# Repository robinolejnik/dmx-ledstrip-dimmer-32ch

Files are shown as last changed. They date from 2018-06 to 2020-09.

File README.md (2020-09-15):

# 32ch DMX LED Strip Dimmer

Arduino Mini and TLC5940 based 32 channel 12V PWM dimmer with [DMX512](https://en.wikipedia.org/wiki/DMX512) and [RDM](https://en.wikipedia.org/wiki/RDM_(lighting)) support.

## Table of contents
* [Features](#features)
* [Building and connecting the PCB](#building-and-connecting-the-pcb)
* [Installing the Software](#installing-the-software)
* [Setting the DMX channel](#setting-the-dmx-channel)
* [Write your own Software](#write-your-own-software)
* [Arduino Pin Configuration](#arduino-pin-configuration)
* [Contributing](#contributing)
* [See also](#see-also)
* [License](#license)

## Features
- 32 channels
- several amps current capability per channel
- high PWM frequency
- [DMX512](https://en.wikipedia.org/wiki/DMX512) with [RDM](https://en.wikipedia.org/wiki/RDM_(lighting)) support
- control LEDs, LED-Strips, Lamps, Motors, Relays, ...

## Building and connecting the PCB
The double sided PCB has surface mounted components on both sides. All resistors and capacitors are 0805 sized parts.
Screw terminals are available for all connections.

### Installing the Software

#### Connecting the Programmer
On the PCB, there is no dedicated programming connector. Instead, directly connect a serial adapter to the Arduino Pro Mini. Make sure that no DMX device is connected to the PCB.

#### Libraries
Install the required libraries within the Arduino IDE
* [tlc5940](https://github.com/PaulStoffregen/Tlc5940) Control of the two TLC5940 ICs
* [dmxserial2](https://github.com/mathertel/DmxSerial2) Used to handle DMX and RDM decoding

Open the [Sketch](dmx_led_strip_dimmer_32ch.ino) with the Arduino IDE, change the DMX address if needed, select the correct serial port and Hardware (Arduino Pro Mini or Arduino Mini) and click Upload.

### Setting the DMX channel
The DMX channel can be preset in the Arduino source code. Later, it can only be changed via RDM ([Remote Device Management](https://en.wikipedia.org/wiki/RDM_(lighting))) commands.

## Write your own Software
The PWM signals are created by two chained TLC5940 PWM LED drivers. Output 1-16 of U7 maps to Output 1-16 on the PCB, output 1-16 of U8 maps to Output 17-32 of the PCB. Per channel, one 74HC04 inverter is used. It is necessary because the PWM controller cannot completely turn off a directly connected N-channel MOSFET. It cannot get it's PWM count down to 0. By inverting the PWM signal, the PCB output can be turned off by fully turning on the TLC5940 channel.

### Arduino pin configuration

| Pin | Function |
| --- | --- |
|  0  | RxD (DMX) |
|  1  | TxD (DMX) |
|  2  | RS485 (DMX) Direction |
|  3  | GSCLK (TLC5940) |
|  9  | XLAT (TLC5940) |
| 10  | BLANK (TLC5940) |
| 11  | SIN (TLC5940) |
| 13  | SCLK (TLC5940) |

Unlisted pins are not connected. The internal voltage regulator on the Arduino Mini Board is not used.

Take a look at the [schematic](schematic.pdf) too. It should clarify things further.

## Contributing
If you want to improve something, feel free to create a pull request.

One thing to optimize is the linear voltage regulator. Maybe someone is interested in fitting a suitable step down converter into the PCB?

## See also

* [TLC5940 datasheet](https://www.ti.com/lit/ds/symlink/tlc5940.pdf)
* [Wikipedia DMX512](https://en.wikipedia.org/wiki/DMX512)
* [Wikipedia RDM](https://en.wikipedia.org/wiki/RDM_(lighting))

## License
[MIT](https://choosealicense.com/licenses/mit/)

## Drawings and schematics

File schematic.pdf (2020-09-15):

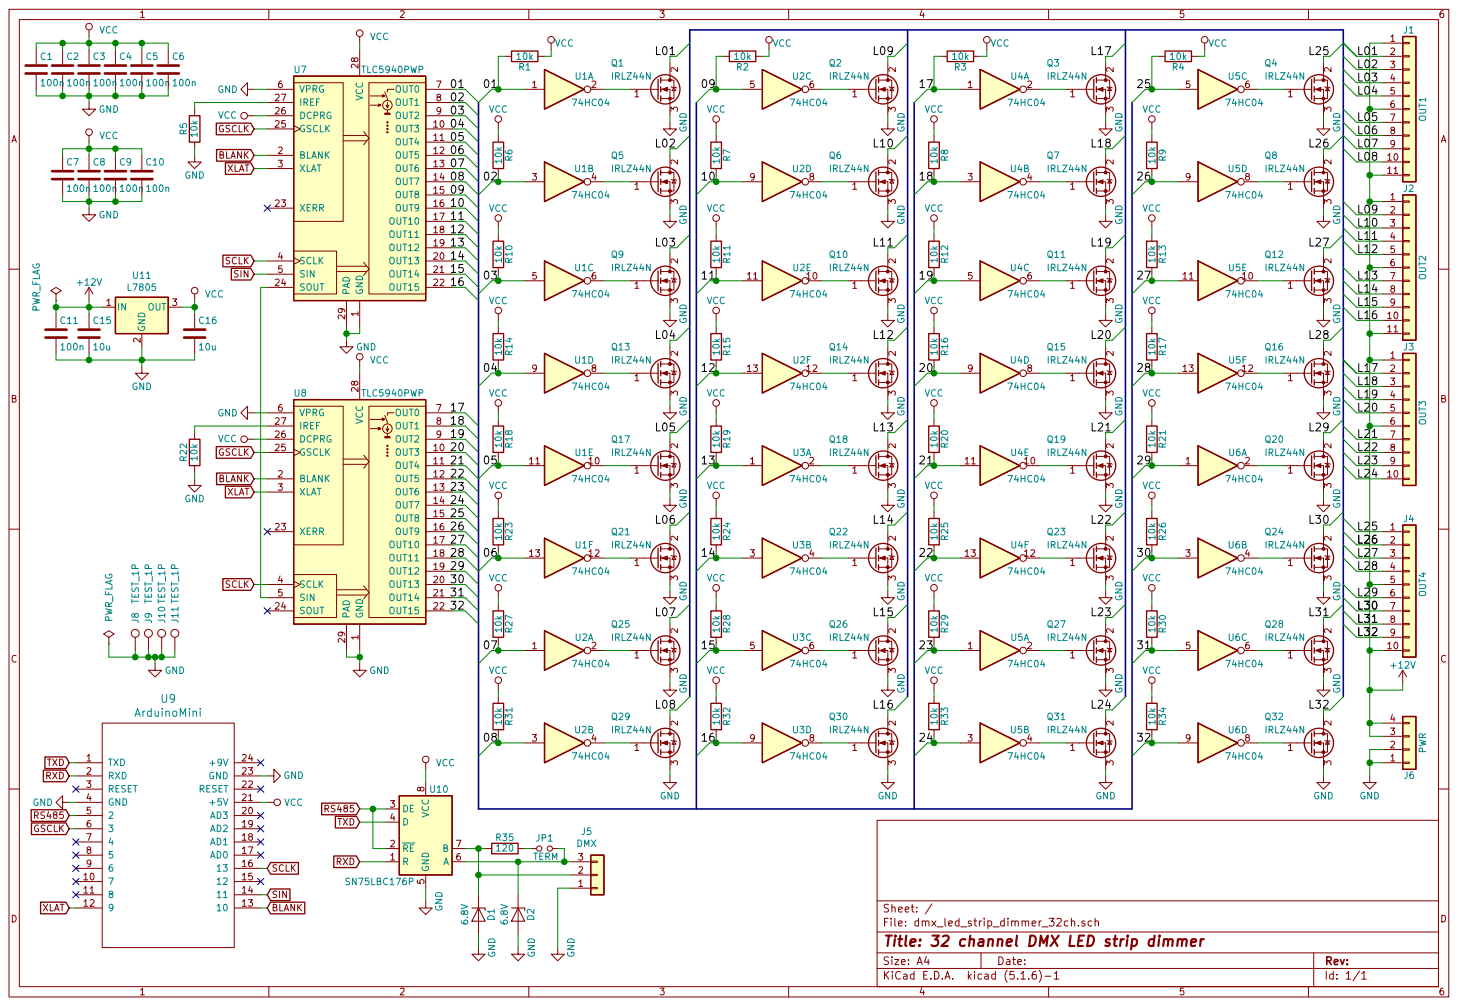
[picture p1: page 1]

1 OUT3 10 OUT4 11 OUT5 12 OUT6 13 OUT7 14 OUT8 15 OUT9 16 OUT10 17 OUT11 18 OUT12 19 BLANK 2 OUT13 20 OUT14 21 OUT15 22 XERR 23 SOUT 24 GSCLK 25 DCPRG 26

File: dmx_led_strip_dimmer_32ch.sch Sheet: /
Id: 1/1 Title: 32 channel DMX LED strip dimmer

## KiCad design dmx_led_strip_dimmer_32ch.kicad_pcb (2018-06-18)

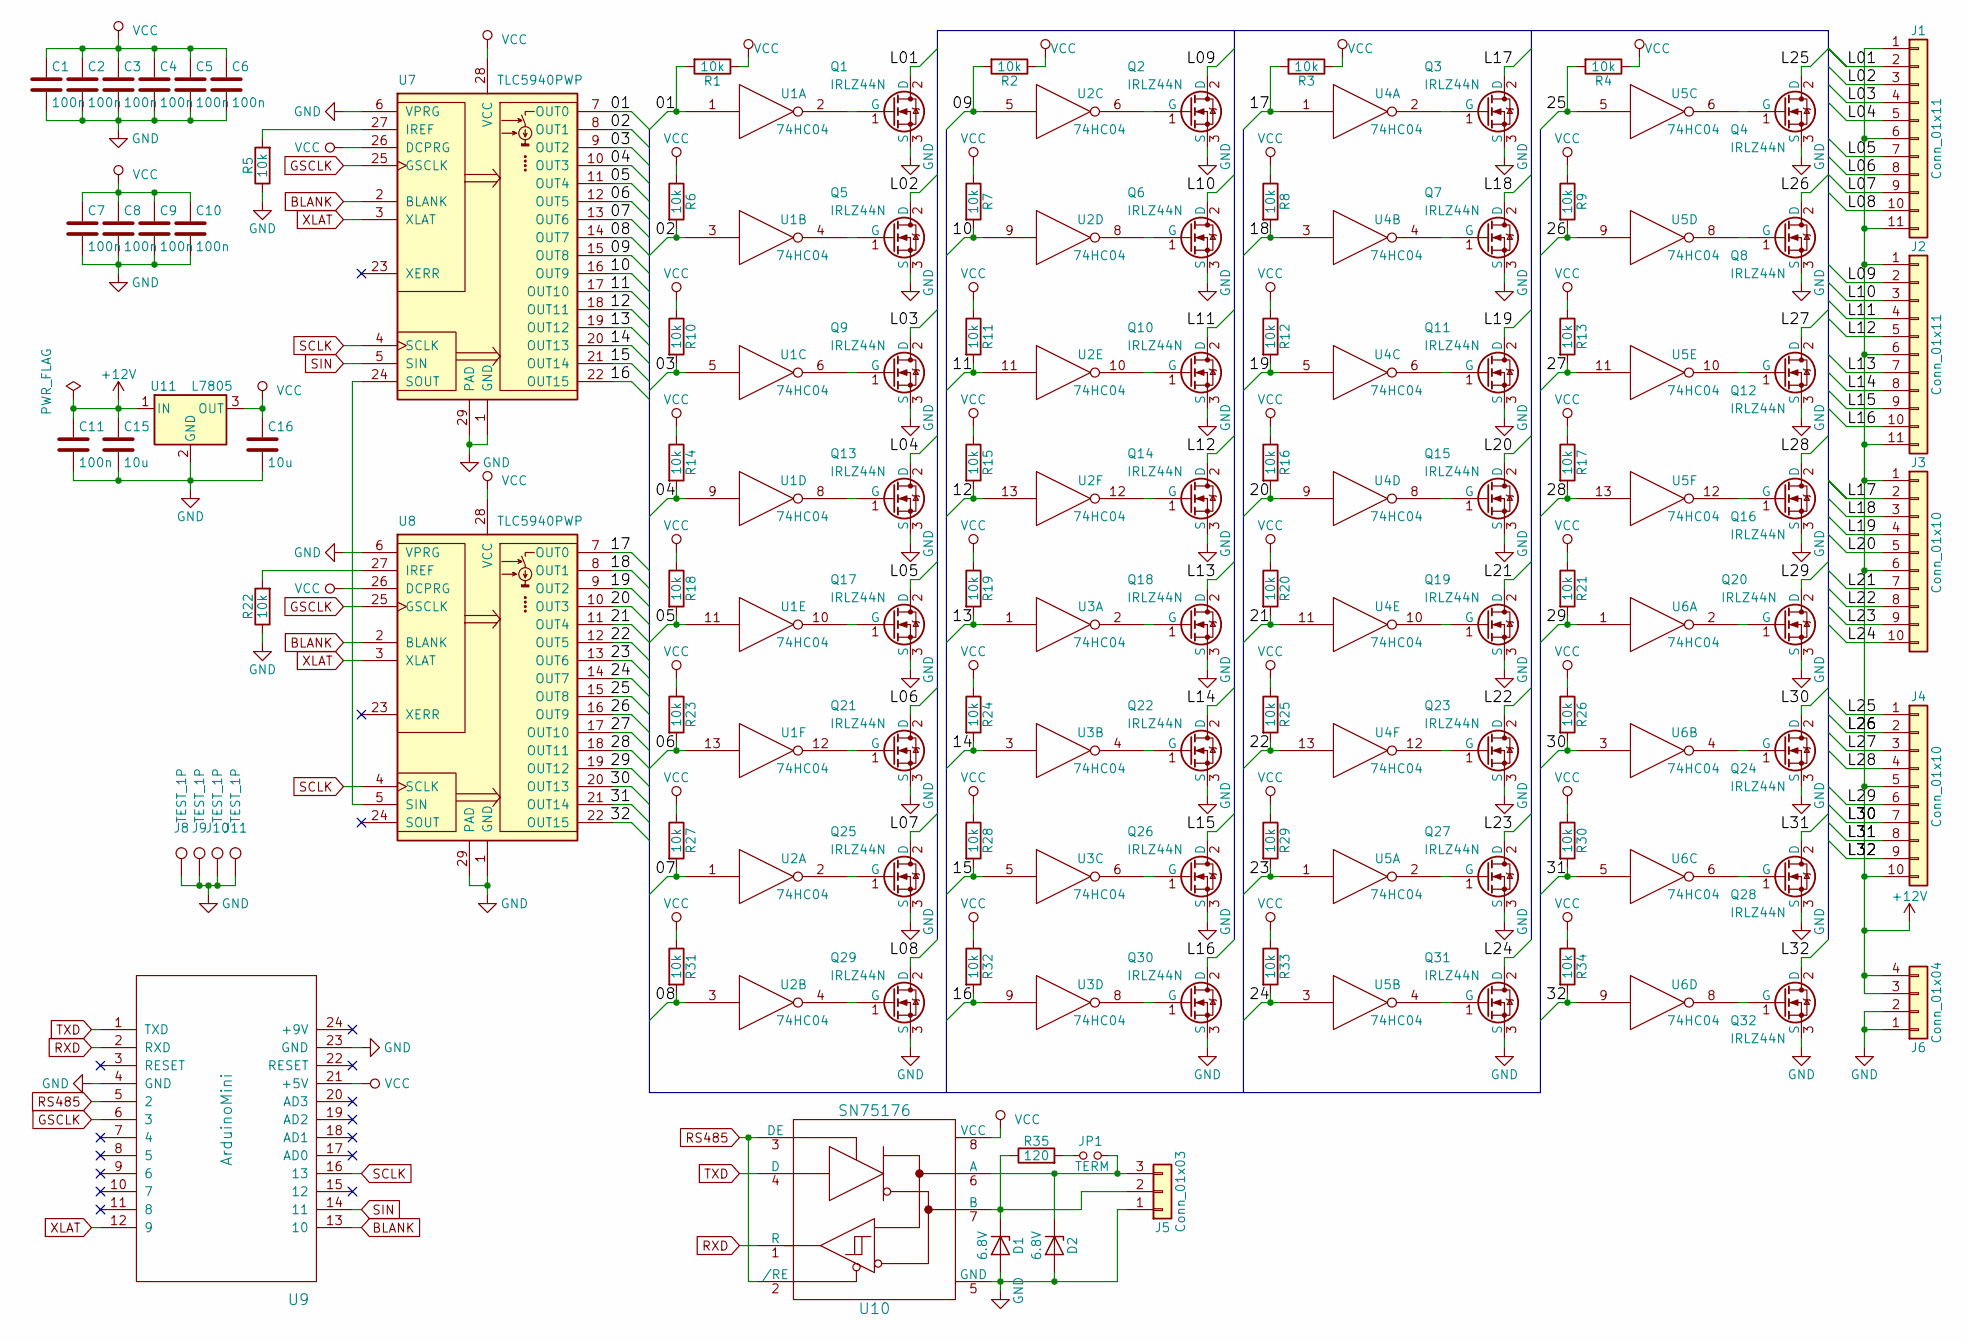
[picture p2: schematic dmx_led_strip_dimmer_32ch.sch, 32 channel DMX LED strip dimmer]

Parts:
C1, C2, C3, C4, C5, C6, C7, C8, C9, C10, C11: 100n; C_0805_HandSoldering
C15, C16: 10u; C_0805_HandSoldering
D1, D2: 6.8V; D_MiniMELF
J1, J2: Conn_01x11; TerminalBlock_Pheonix_MKDS1.5-11pol
J3, J4: Conn_01x10; TerminalBlock_Pheonix_MKDS1.5-10pol
J5: Conn_01x03; TerminalBlock_Pheonix_MKDS1.5-3pol
J6: Conn_01x04; TerminalBlock_Pheonix_MKDS1.5-4pol
J8, J9, J10, J11: TEST_1P; MountingHole_3.2mm_M3_ISO7380_Pad
JP1: TERM; Pin_Header_Straight_1x02_Pitch2.54mm
Q1, Q2, Q3, Q4, Q5, Q6, Q7, Q8, Q9, Q10, Q11, Q12, Q13, Q14, Q15, Q16, Q17, Q18, Q19, Q20, Q21, Q22, Q23, Q24, Q25, Q26, Q27, Q28, Q29, Q30, Q31, Q32: IRLZ44N; TO-220_Vertical
R1, R2, R3, R4, R5, R6, R7, R8, R9, R10, R11, R12, R13, R14, R15, R16, R17, R18, R19, R20, R21, R22, R23, R24, R25, R26, R27, R28, R29, R30, R31, R32, R33, R34: 10k; R_0805_HandSoldering
R35: 120; R_0805_HandSoldering
U1, U2, U3, U4, U5, U6: 74HC04; SOIC-14_3.9x8.7mm_Pitch1.27mm
U7, U8: TLC5940PWP; TSSOP-28_4.4x9.7mm_Pitch0.65mm
U9: ArduinoMini; DIP-24_W15.24mm_LongPads
U10: SN75176; SOIC-8_3.9x4.9mm_Pitch1.27mm
U11: L7805; TO-220-3_Vertical

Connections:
+12V: C11.1, C15.1, J1.1, J1.6, J1.11, J2.1, J2.6, J2.11, J3.1, J3.6, J4.5, J4.10, J6.3, J6.4, U11.1 (IN)
/01: R1.2, U1.1, U7.7 (OUT0)
/02: R6.2, U1.3, U7.8 (OUT1)
/03: R10.2, U1.5, U7.9 (OUT2)
/04: R14.2, U1.9, U7.10 (OUT3)
/05: R18.2, U1.11, U7.11 (OUT4)
/06: R23.2, U1.13, U7.12 (OUT5)
/07: R27.2, U2.1, U7.13 (OUT6)
/08: R31.2, U2.3, U7.14 (OUT7)
/09: R2.2, U2.5, U7.15 (OUT8)
/10: R7.2, U2.9, U7.16 (OUT9)
/11: R11.2, U2.11, U7.17 (OUT10)
/12: R15.2, U2.13, U7.18 (OUT11)
/13: R19.2, U3.1, U7.19 (OUT12)
/14: R24.2, U3.3, U7.20 (OUT13)
/15: R28.2, U3.5, U7.21 (OUT14)
/16: R32.2, U3.9, U7.22 (OUT15)
/17: R3.2, U4.1, U8.7 (OUT0)
/18: R8.2, U4.3, U8.8 (OUT1)
/19: R12.2, U4.5, U8.9 (OUT2)
/20: R16.2, U4.9, U8.10 (OUT3)
/21: R20.2, U4.11, U8.11 (OUT4)
/22: R25.2, U4.13, U8.12 (OUT5)
/23: R29.2, U5.1, U8.13 (OUT6)
/24: R33.2, U5.3, U8.14 (OUT7)
/25: R4.2, U5.5, U8.15 (OUT8)
/26: R9.2, U5.9, U8.16 (OUT9)
/27: R13.2, U5.11, U8.17 (OUT10)
/28: R17.2, U5.13, U8.18 (OUT11)
/29: R21.2, U6.1, U8.19 (OUT12)
/30: R26.2, U6.3, U8.20 (OUT13)
/31: R30.2, U6.5, U8.21 (OUT14)
/32: R34.2, U6.9, U8.22 (OUT15)
/L01: J1.2, Q1.2 (D)
/L02: J1.3, Q5.2 (D)
/L03: J1.4, Q9.2 (D)
/L04: J1.5, Q13.2 (D)
/L05: J1.7, Q17.2 (D)
/L06: J1.8, Q21.2 (D)
/L07: J1.9, Q25.2 (D)
/L08: J1.10, Q29.2 (D)
/L09: J2.2, Q2.2 (D)
/L10: J2.3, Q6.2 (D)
/L11: J2.4, Q10.2 (D)
/L12: J2.5, Q14.2 (D)
/L13: J2.7, Q18.2 (D)
/L14: J2.8, Q22.2 (D)
/L15: J2.9, Q26.2 (D)
/L16: J2.10, Q30.2 (D)
/L17: J3.2, Q3.2 (D)
/L18: J3.3, Q7.2 (D)
/L19: J3.4, Q11.2 (D)
/L20: J3.5, Q15.2 (D)
/L21: J3.7, Q19.2 (D)
/L22: J3.8, Q23.2 (D)
/L23: J3.9, Q27.2 (D)
/L24: J3.10, Q31.2 (D)
/L25: J4.1, Q4.2 (D)
/L26: J4.2, Q8.2 (D)
/L27: J4.3, Q12.2 (D)
/L28: J4.4, Q16.2 (D)
/L29: J4.6, Q20.2 (D)
/L30: J4.7, Q24.2 (D)
/L31: J4.8, Q28.2 (D)
/L32: J4.9, Q32.2 (D)
BLANK: U7.2 (BLANK), U8.2 (BLANK), U9.13 (10)
GND: C1.2, C2.2, C3.2, C4.2, C5.2, C6.2, C7.2, C8.2, C9.2, C10.2, C11.2, C15.2, C16.2, D1.2 (A), D2.2 (A), J5.1, J6.1, J6.2, J8.1, J9.1, J10.1, J11.1, Q1.3 (S), Q2.3 (S), Q3.3 (S), Q4.3 (S), Q5.3 (S), Q6.3 (S), Q7.3 (S), Q8.3 (S), Q9.3 (S), Q10.3 (S), Q11.3 (S), Q12.3 (S), Q13.3 (S), Q14.3 (S), Q15.3 (S), Q16.3 (S), Q17.3 (S), Q18.3 (S), Q19.3 (S), Q20.3 (S), Q21.3 (S), Q22.3 (S), Q23.3 (S), Q24.3 (S), Q25.3 (S), Q26.3 (S), Q27.3 (S), Q28.3 (S), Q29.3 (S), Q30.3 (S), Q31.3 (S), Q32.3 (S), R5.1, R22.1, U1.7 (GND), U2.7 (GND), U3.7 (GND), U4.7 (GND), U5.7 (GND), U6.7 (GND), U7.1 (GND), U7.6 (VPRG), U7.29 (PAD), U8.1 (GND), U8.6 (VPRG), U8.29 (PAD), U9.4 (GND), U9.23 (GND), U10.5 (GND), U11.2 (GND)
GSCLK: U7.25 (GSCLK), U8.25 (GSCLK), U9.6 (3)
unnamed: D1.1 (K), J5.2, R35.1, U10.7 (B)
unnamed: D2.1 (K), J5.3, JP1.2, U10.6 (A)
unnamed: JP1.1, R35.2
unnamed: Q1.1 (G), U1.2
unnamed: Q2.1 (G), U2.6
unnamed: Q3.1 (G), U4.2
unnamed: Q4.1 (G), U5.6
unnamed: Q5.1 (G), U1.4
unnamed: Q6.1 (G), U2.8
unnamed: Q7.1 (G), U4.4
unnamed: Q8.1 (G), U5.8
unnamed: Q9.1 (G), U1.6
unnamed: Q10.1 (G), U2.10
unnamed: Q11.1 (G), U4.6
unnamed: Q12.1 (G), U5.10
unnamed: Q13.1 (G), U1.8
unnamed: Q14.1 (G), U2.12
unnamed: Q15.1 (G), U4.8
unnamed: Q16.1 (G), U5.12
unnamed: Q17.1 (G), U1.10
unnamed: Q18.1 (G), U3.2
unnamed: Q19.1 (G), U4.10
unnamed: Q20.1 (G), U6.2
unnamed: Q21.1 (G), U1.12
unnamed: Q22.1 (G), U3.4
unnamed: Q23.1 (G), U4.12
unnamed: Q24.1 (G), U6.4
unnamed: Q25.1 (G), U2.2
unnamed: Q26.1 (G), U3.6
unnamed: Q27.1 (G), U5.2
unnamed: Q28.1 (G), U6.6
unnamed: Q29.1 (G), U2.4
unnamed: Q30.1 (G), U3.8
unnamed: Q31.1 (G), U5.4
unnamed: Q32.1 (G), U6.8
unnamed: R5.2, U7.27 (IREF)
unnamed: R22.2, U8.27 (IREF)
unnamed: U7.24 (SOUT), U8.5 (SIN)
RS485: U9.5 (2), U10.2 (/RE), U10.3 (DE)
RXD: U9.2 (RXD), U10.1 (R)
SCLK: U7.4 (SCLK), U8.4 (SCLK), U9.16 (13)
SIN: U7.5 (SIN), U9.14 (11)
TXD: U9.1 (TXD), U10.4 (D)
VCC: C1.1, C2.1, C3.1, C4.1, C5.1, C6.1, C7.1, C8.1, C9.1, C10.1, C16.1, R1.1, R2.1, R3.1, R4.1, R6.1, R7.1, R8.1, R9.1, R10.1, R11.1, R12.1, R13.1, R14.1, R15.1, R16.1, R17.1, R18.1, R19.1, R20.1, R21.1, R23.1, R24.1, R25.1, R26.1, R27.1, R28.1, R29.1, R30.1, R31.1, R32.1, R33.1, R34.1, U1.14 (VCC), U2.14 (VCC), U3.14 (VCC), U4.14 (VCC), U5.14 (VCC), U6.14 (VCC), U7.26 (DCPRG), U7.28 (VCC), U8.26 (DCPRG), U8.28 (VCC), U9.21 (+5V), U10.8 (VCC), U11.3 (OUT)
XLAT: U7.3 (XLAT), U8.3 (XLAT), U9.12 (9)

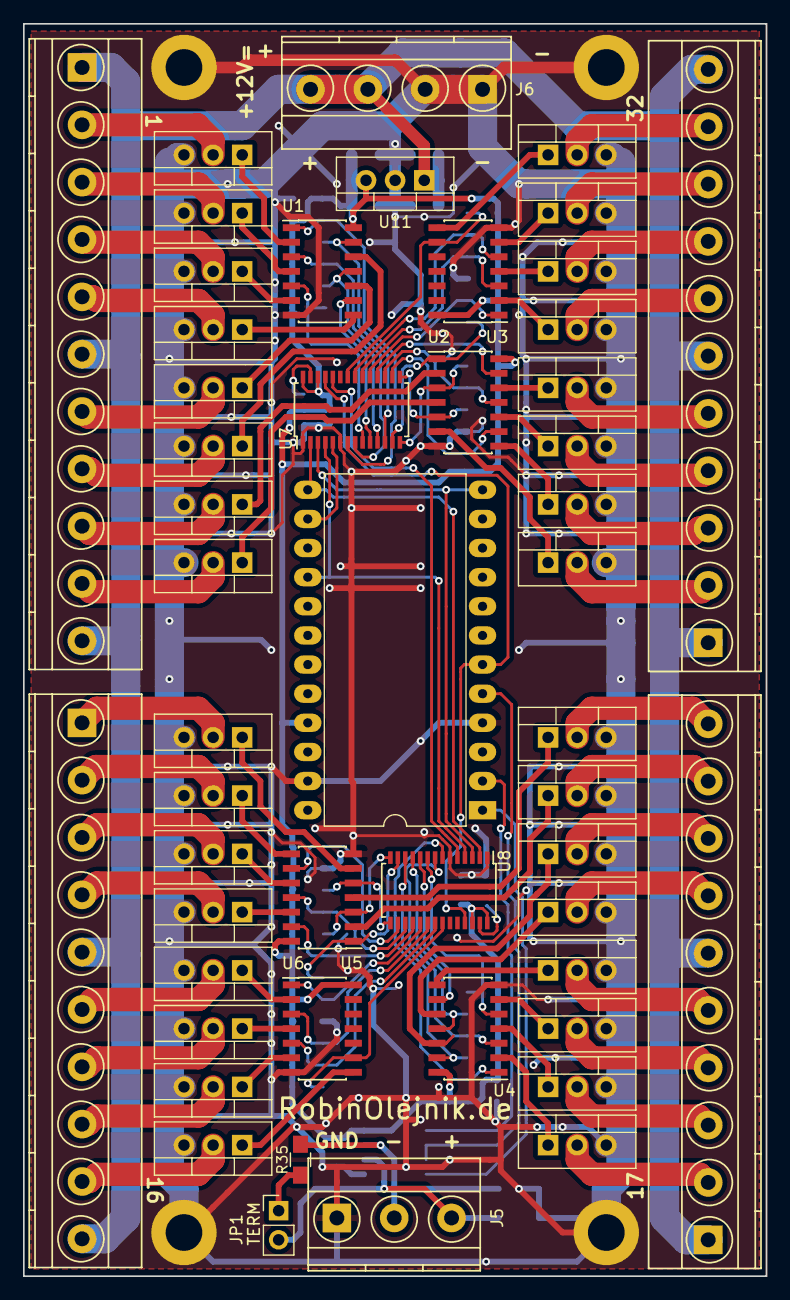
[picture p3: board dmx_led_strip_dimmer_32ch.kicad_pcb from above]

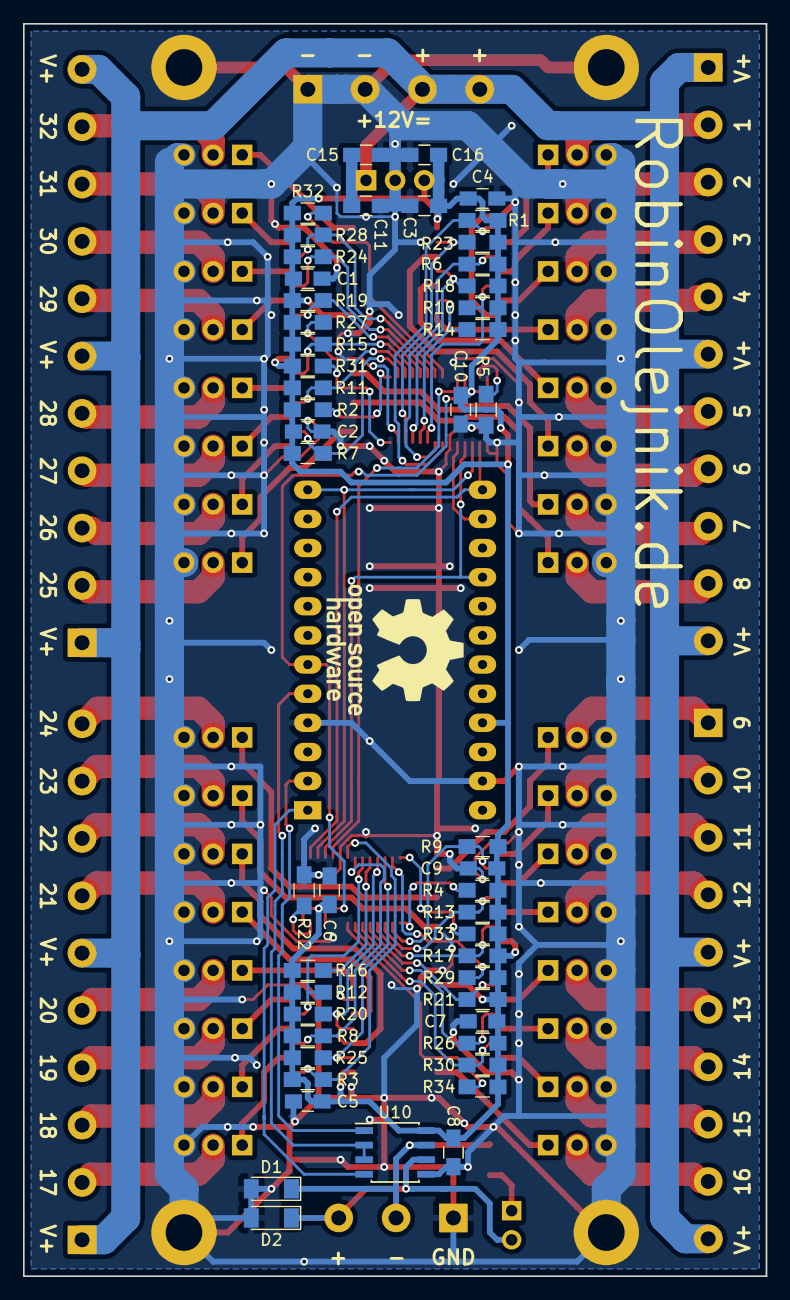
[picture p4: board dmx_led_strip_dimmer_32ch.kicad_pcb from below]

Board: 2 copper layers, 64.8 x 109.2 mm, 104 parts (50 on the bottom side), 113 nets.

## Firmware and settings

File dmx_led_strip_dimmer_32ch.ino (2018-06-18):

#include <EEPROM.h>
#include <DMXSerial2.h>
#include "Tlc5940.h"

#define RS485_PIN 2

const uint8_t channelMapping[] = {0, 1, 2, 3, 4, 5, 6, 7, 24, 25, 26, 27, 28, 29, 30, 31, 16, 17, 18, 19, 20, 21, 22, 23, 8, 9, 10, 11, 12, 13, 14, 15};

const uint16_t my_pids[] = {};
struct RDMINIT rdmInit = {
  "RobinOlejnik.de",
  1,
  "32ch_dmx_led_strip_dimmer",
  32,
  (sizeof(my_pids) / sizeof(uint16_t)), my_pids
};


void setup () {
  DMXSerial2.init(&rdmInit, processCommand, RS485_PIN, LOW, HIGH);
  Tlc.init();
}


void loop() {
  unsigned long lastPacket = DMXSerial2.noDataSince();
  Tlc.clear();

  if (DMXSerial2.isIdentifyMode()) {
    unsigned long now = millis();
    if (now % 1000 < 500) {
      for (unsigned char i = 0; i < 32; i++) {
        Tlc.set(i, 4095);
      }
    } else {
      for (unsigned char i = 0; i < 32; i++) {
        Tlc.set(i, 0);
      }
    }

  } else if (lastPacket < 5000) {
    for (unsigned char i = 0; i < 32; i++) {
      Tlc.set(channelMapping[i], DMXSerial2.readRelative(i) * 16);
    }
  } else {
    for (unsigned char i = 0; i < 32; i++) {
      Tlc.set(i, 0);
    }
  }
  Tlc.update();
  DMXSerial2.tick();
}

bool8 processCommand(struct RDMDATA *rdm, uint16_t *nackReason) {
  return false;
}

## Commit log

2018-06-18 Added pcb files
    [dmx_led_strip_dimmer_32ch.kicad_pcb, dmx_led_strip_dimmer_32ch.sch]
2018-06-18 Added arduino sketch
2019-03-06 Updated schematic to KiCad 5
    [dmx_led_strip_dimmer_32ch.sch]
2019-03-06 Archived project for better portability
    [dmx_led_strip_dimmer_32ch.sch]
2020-09-15 Added schematic.pdf
